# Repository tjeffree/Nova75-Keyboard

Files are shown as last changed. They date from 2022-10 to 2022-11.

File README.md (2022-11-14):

# Nova75

A 75 key ortholinear keyboard designed as a RP2040 powered version of keyboards like the ID75/XD75.

---

## Looks like this
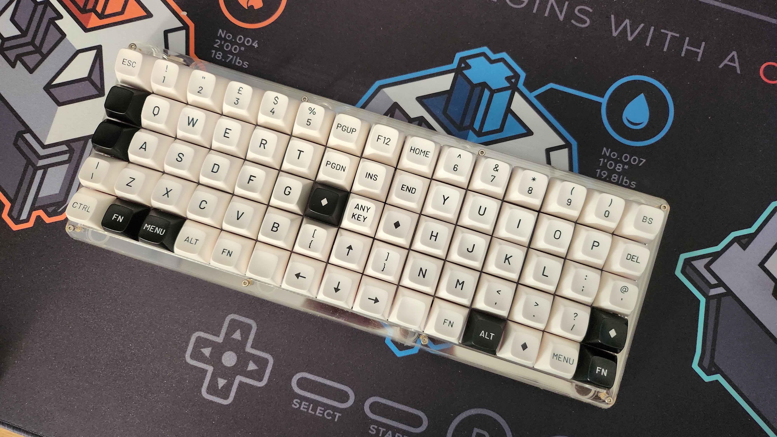
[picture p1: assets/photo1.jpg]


---
## Fab Help

The provided files have been used with JLCPCB. If you're using another fab generate the files according to their specifications.

If you are using JLCPCB (and they have the parts in stock) then head over to JLCPCB and upload the gerber in `jlcpcb/gerber`.

Using mostly the defaults on the order screen check the following:

**Main**
* Dimensions `284.7` x `94.21`
* PCB Color - Whatever you like
* Surface Finish - Whatever you can afford
* Remover Order Number - Specify a location (it's already specified)

**PCB Assembly**
* PCB Assembly - Yes
* Assemble bottom side
* Tooling holes - Added by Customer
* Confirm Parts Placement - Yes

**BOM and Placement**

For the BOM use: `jlcpcb/assembly/BOM-nova75.csv`

For the CPL use: `jlcpcb/assembly/POS-nova75.csv`

Select the PCB description - Office / Keyboard

The next screen should be a list of parts, something like this where you can find out if they have everything:

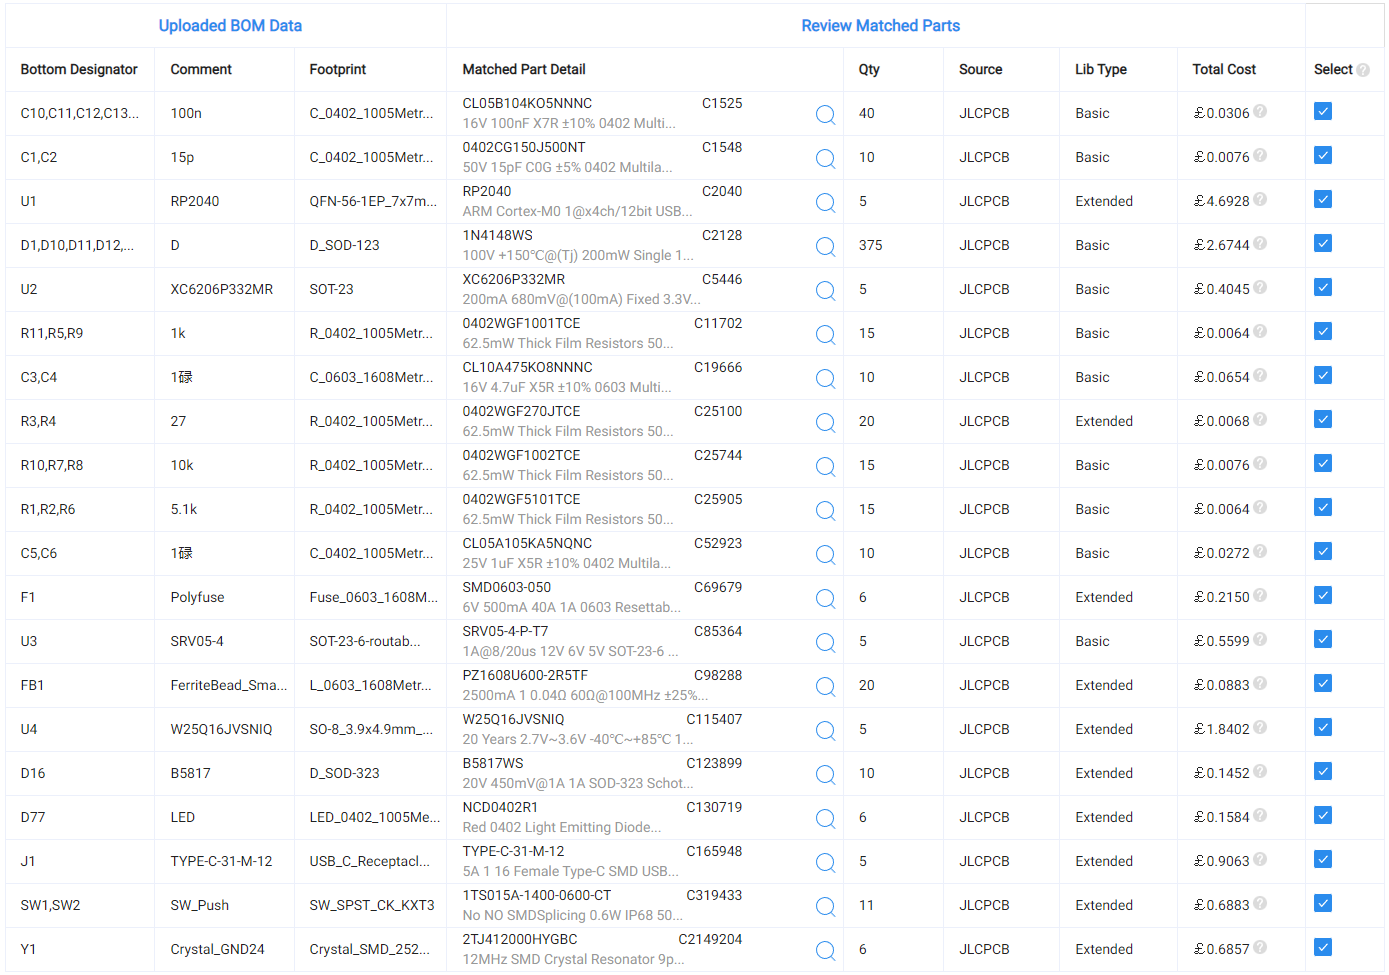
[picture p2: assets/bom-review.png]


Continue on to the placement. Previously all holes lined up, but for some reason JLC preview is not working right now, so the preview will look similar to this with the holes misaligned:

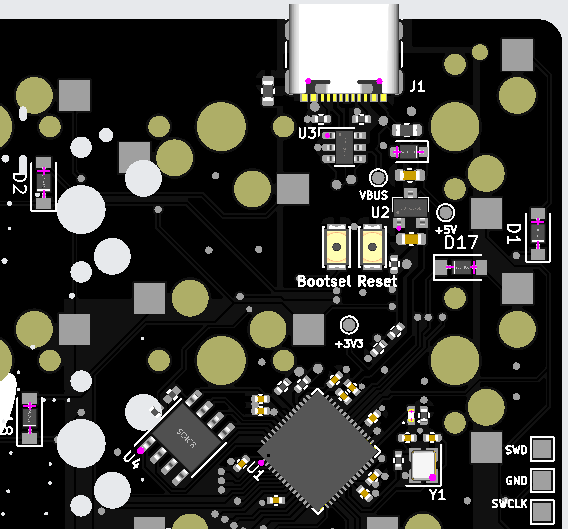
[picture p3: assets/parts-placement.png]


Rotate components the correct way. JLC will check best they can, but you need to do this too.

**That's it. Now wait.**

## Case

The `Case & Plates` dir has some stl files for 3D printing the plates.

Also included is a zip containing the dxf files I sent off for the stacked acrylic case seen below.

## Couple more pictures

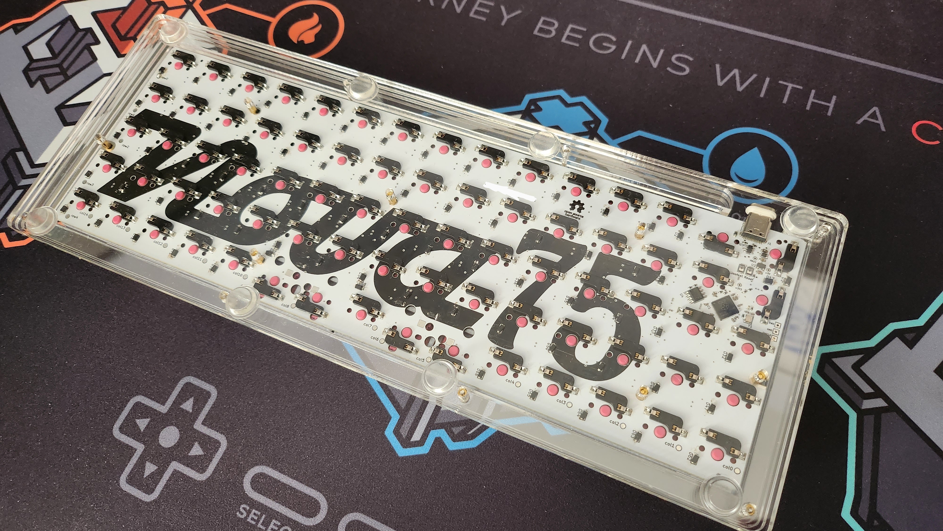
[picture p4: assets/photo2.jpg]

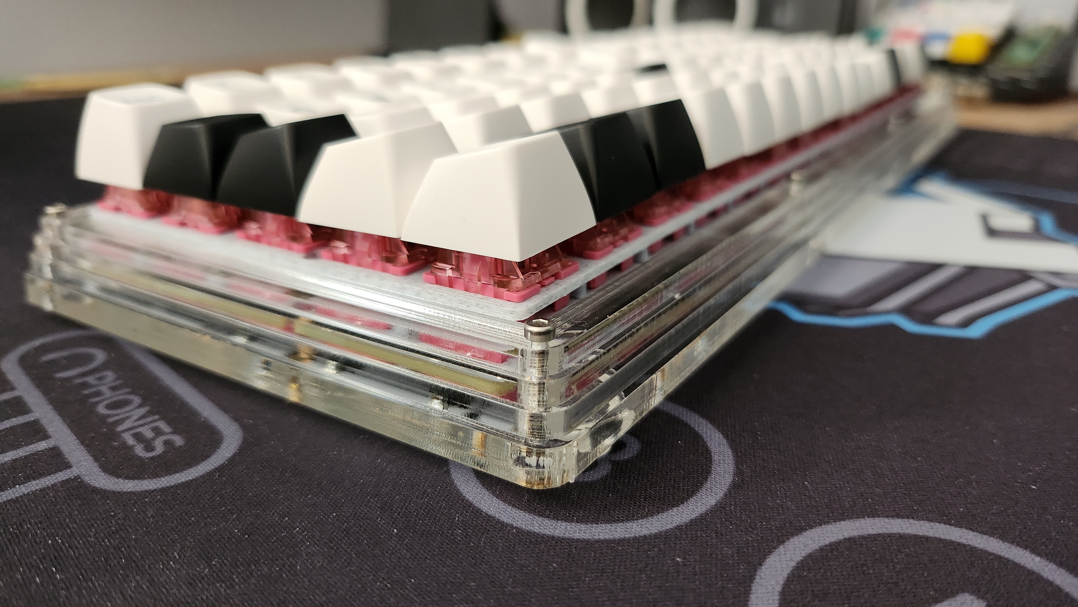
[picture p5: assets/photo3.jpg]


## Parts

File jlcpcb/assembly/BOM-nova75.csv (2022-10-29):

Comment | Designator | Footprint | LCSC
W25Q16JVSNIQ | U4 | SO-8_3.9x4.9mm_P1.27mm | C115407
1k | R11,R5,R9 | R_0402_1005Metric | C11702
B5817 | D16 | D_SOD-323 | C123899
LED | D77 | LED_0402_1005Metric | C130719
100n | C10,C11,C12,C13,C14,C7,C8,C9 | C_0402_1005Metric | C1525
15p | C1,C2 | C_0402_1005Metric | C1548
TYPE-C-31-M-12 | J1 | USB_C_Receptacle_HRO_TYPE-C-31-M-12 | C165948
1µ | C3,C4 | C_0603_1608Metric | C19666
RP2040 | U1 | QFN-56-1EP_7x7mm_P0.4mm_EP3.2x3.2mm | C2040
D | D1,D10,D11,D12,D13,D14,D15,D17,D18,D19,D2,D20,D21,D22,D23,D24,D25,D26,D27,D28,D29,D3,D30,D31,D32,D33,D34,D35,D36,D37,D38,D39,D4,D40,D41,D42,D43,D44,D45,D46,D47,D48,D49,D5,D50,D51,D52,D53,D54,D55,D56,D57,D58,D59,D6,D60,D61,D62,D63,D64,D65,D66,D67,D68,D69,D7,D70,D71,D72,D73,D74,D75,D76,D8,D9 | D_SOD-123 | C2128
Crystal_GND24 | Y1 | Crystal_SMD_2520-4Pin_2.5x2.0mm | C2149204
27 | R3,R4 | R_0402_1005Metric | C25100
10k | R10,R7,R8 | R_0402_1005Metric | C25744
5.1k | R1,R2,R6 | R_0402_1005Metric | C25905
SW_Push | SW1,SW2 | SW_SPST_CK_KXT3 | C319433
1µ | C5,C6 | C_0402_1005Metric | C52923
XC6206P332MR | U2 | SOT-23 | C5446
Polyfuse | F1 | Fuse_0603_1608Metric | C69679
SRV05-4 | U3 | SOT-23-6-routable | C85364
FerriteBead_Small | FB1 | L_0603_1608Metric | C98288
KEYSW | K57 | MXOnly-1U-Hotswap
KEYSW | K72 | MXOnly-1U-Hotswap
KEYSW | K71 | MXOnly-1U-Hotswap
KEYSW | K70 | MXOnly-1U-Hotswap
KEYSW | K69 | MXOnly-2U-Hotswap-ReversedStabilizers
KEYSW | K68 | MXOnly-1U-Hotswap
KEYSW | K66 | MXOnly-2U-Hotswap-ReversedStabilizers
KEYSW | K64 | MXOnly-1U-Hotswap
KEYSW | K63 | MXOnly-1U-Hotswap
KEYSW | K62 | MXOnly-1U-Hotswap
KEYSW | K61 | MXOnly-1U-Hotswap
KEYSW | K60 | MXOnly-1U-Hotswap
KEYSW | K59 | MXOnly-1U-Hotswap
KEYSW | K58 | MXOnly-1U-Hotswap
KEYSW | K56 | MXOnly-1U-Hotswap
KEYSW | K55 | MXOnly-1U-Hotswap
KEYSW | K54 | MXOnly-1U-Hotswap
KEYSW | K53 | MXOnly-1U-Hotswap
KEYSW | K52 | MXOnly-1U-Hotswap
KEYSW | K51 | MXOnly-1U-Hotswap
KEYSW | K50 | MXOnly-1U-Hotswap
KEYSW | K49 | MXOnly-1U-Hotswap
KEYSW | K48 | MXOnly-1U-Hotswap
KEYSW | K47 | MXOnly-1U-Hotswap
KEYSW | K46 | MXOnly-1U-Hotswap
KEYSW | K45 | MXOnly-1U-Hotswap
KEYSW | K44 | MXOnly-1U-Hotswap
KEYSW | K43 | MXOnly-1U-Hotswap
KEYSW | K42 | MXOnly-1U-Hotswap
KEYSW | K41 | MXOnly-1U-Hotswap
KEYSW | K40 | MXOnly-1U-Hotswap
KEYSW | K39 | MXOnly-1U-Hotswap
KEYSW | K38 | MXOnly-1U-Hotswap
KEYSW | K37 | MXOnly-1U-Hotswap
KEYSW | K36 | MXOnly-1U-Hotswap
KEYSW | K35 | MXOnly-1U-Hotswap
KEYSW | K34 | MXOnly-1U-Hotswap
KEYSW | K33 | MXOnly-1U-Hotswap
KEYSW | K32 | MXOnly-1U-Hotswap
KEYSW | K31 | MXOnly-1U-Hotswap
KEYSW | K30 | MXOnly-1U-Hotswap
KEYSW | K29 | MXOnly-1U-Hotswap
KEYSW | K28 | MXOnly-1U-Hotswap
KEYSW | K27 | MXOnly-1U-Hotswap
KEYSW | K26 | MXOnly-1U-Hotswap
KEYSW | K25 | MXOnly-1U-Hotswap
KEYSW | K24 | MXOnly-1U-Hotswap
KEYSW | K23 | MXOnly-1U-Hotswap
KEYSW | K22 | MXOnly-1U-Hotswap
KEYSW | K21 | MXOnly-1U-Hotswap
KEYSW | K20 | MXOnly-1U-Hotswap
KEYSW | K19 | MXOnly-1U-Hotswap
KEYSW | K18 | MXOnly-1U-Hotswap
KEYSW | K17 | MXOnly-1U-Hotswap
KEYSW | K16 | MXOnly-1U-Hotswap
KEYSW | K15 | MXOnly-1U-Hotswap
KEYSW | K14 | MXOnly-1U-Hotswap
KEYSW | K13 | MXOnly-1U-Hotswap
KEYSW | K12 | MXOnly-1U-Hotswap
KEYSW | K11 | MXOnly-1U-Hotswap
KEYSW | K10 | MXOnly-1U-Hotswap
KEYSW | K9 | MXOnly-1U-Hotswap
KEYSW | K8 | MXOnly-1U-Hotswap
KEYSW | K7 | MXOnly-1U-Hotswap
KEYSW | K6 | MXOnly-1U-Hotswap
KEYSW | K5 | MXOnly-1U-Hotswap
KEYSW | K4 | MXOnly-1U-Hotswap
KEYSW | K3 | MXOnly-1U-Hotswap
KEYSW | K2 | MXOnly-1U-Hotswap
KEYSW | K1 | MXOnly-1U-Hotswap
KEYSW | K65 | MXOnly-1U-Hotswap
MountingHole | H6 | MountingHole_2.2mm_M2_elongated
ToolingHole | H5 | Tooling-Hole
KEYSW | K67 | MXOnly-1U-Hotswap
MountingHole | H4 | MountingHole_2.2mm_M2_elongated
ToolingHole | H3 | Tooling-Hole
MountingHole | H2 | MountingHole_2.2mm_M2_elongated
ToolingHole | H1 | Tooling-Hole
MountingHole | H8 | MountingHole_2.2mm_M2_elongated
ToolingHole | H7 | Tooling-Hole
MountingHole | H9 | MountingHole_2.2mm_M2_elongated
TestPoint | TP26 | TestPoint_THTPad_D1.0mm_Drill0.5mm
TestPoint | TP9 | TestPoint_THTPad_D1.0mm_Drill0.5mm
TestPoint | TP8 | TestPoint_THTPad_D1.0mm_Drill0.5mm
TestPoint | TP25 | TestPoint_Pad_D1.5mm
TestPoint | TP24 | TestPoint_Pad_D1.5mm
TestPoint | TP23 | TestPoint_Pad_D1.5mm
TestPoint | TP22 | TestPoint_Pad_D1.5mm
TestPoint | TP21 | TestPoint_Pad_D1.5mm
TestPoint | TP20 | TestPoint_Pad_D1.5mm
TestPoint | TP19 | TestPoint_Pad_D1.5mm
TestPoint | TP18 | TestPoint_Pad_D1.5mm
TestPoint | TP17 | TestPoint_Pad_D1.5mm
TestPoint | TP16 | TestPoint_Pad_D1.5mm
TestPoint | TP15 | TestPoint_Pad_D1.5mm
TestPoint | TP14 | TestPoint_Pad_D1.5mm
TestPoint | TP13 | TestPoint_Pad_D1.5mm
TestPoint | TP12 | TestPoint_Pad_D1.5mm
TestPoint | TP11 | TestPoint_Pad_D1.5mm
TestPoint | TP10 | TestPoint_Pad_D1.5mm
TestPoint | TP7 | TestPoint_THTPad_1.5x1.5mm_Drill0.7mm
TestPoint | TP6 | TestPoint_THTPad_1.5x1.5mm_Drill0.7mm
TestPoint | TP5 | TestPoint_THTPad_1.5x1.5mm_Drill0.7mm
TestPoint | TP4 | TestPoint_Pad_D1.5mm
TestPoint | TP3 | TestPoint_Pad_D1.5mm
TestPoint | TP2 | TestPoint_Pad_D1.5mm
TestPoint | TP1 | TestPoint_Pad_D1.5mm
KEYSW | K76 | MXOnly-1U-Hotswap
KEYSW | K73 | MXOnly-1U-Hotswap
KEYSW | K75 | MXOnly-1U-Hotswap
KEYSW | K74 | MXOnly-1U-Hotswap
KEYSW | K77 | MXOnly-1U-Hotswap

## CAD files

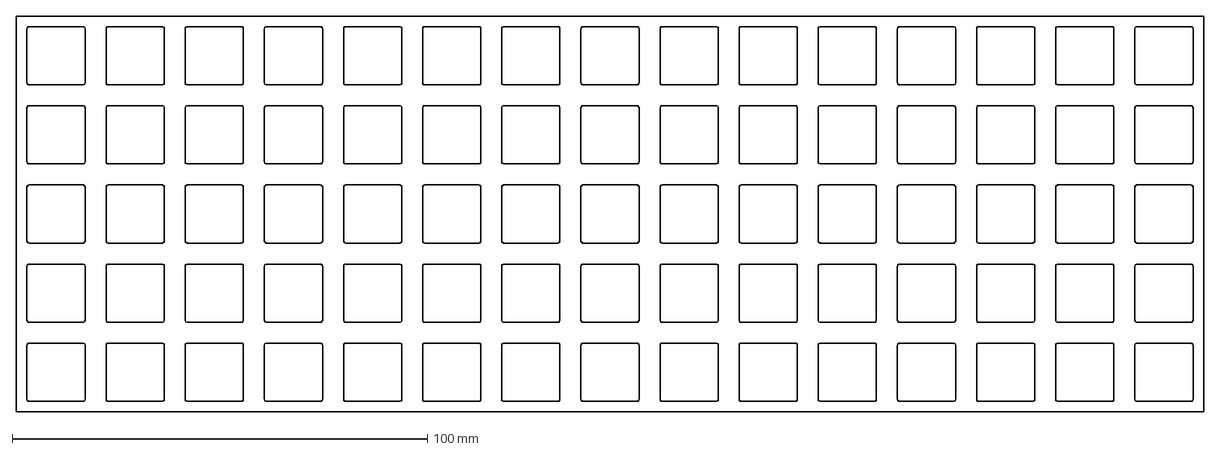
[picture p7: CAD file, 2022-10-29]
assets/plate-2022-09-08T15_52_23.619Z.dxf
285.8 x 95.2 mm

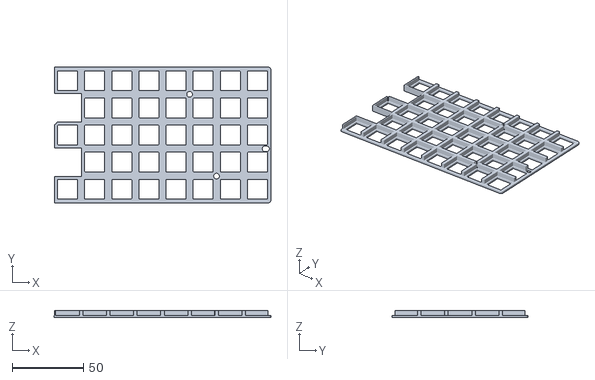
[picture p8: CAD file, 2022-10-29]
Case & Plates/Right.stl
152.4 x 95.2 x 5.00

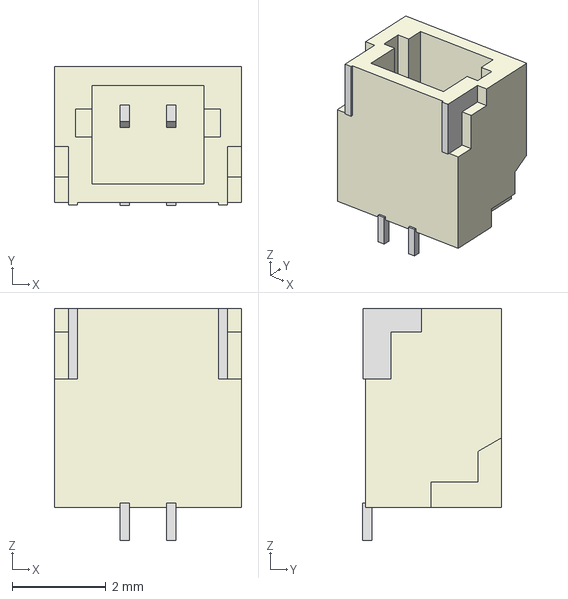
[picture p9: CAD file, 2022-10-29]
marbastlib-main/3d/CON_SM02B-SRSS-TB.step
4.00 x 2.96 x 4.95 mm

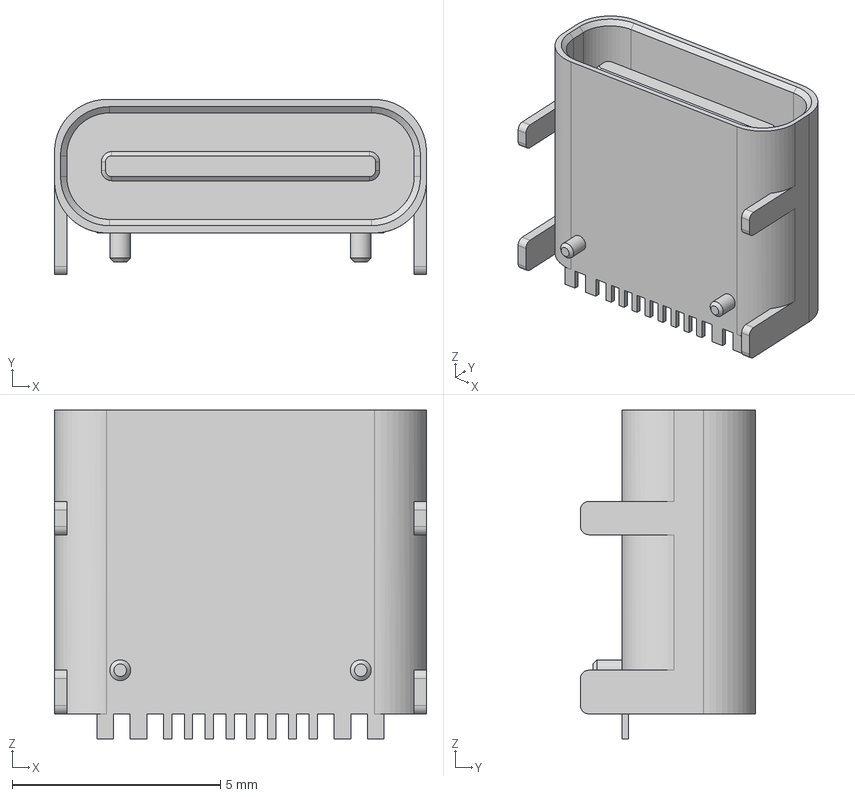
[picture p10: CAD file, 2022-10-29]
Type-C.pretty-master/HRO TYPE-C-31-M-12.step
8.94 x 4.21 x 7.90 mm

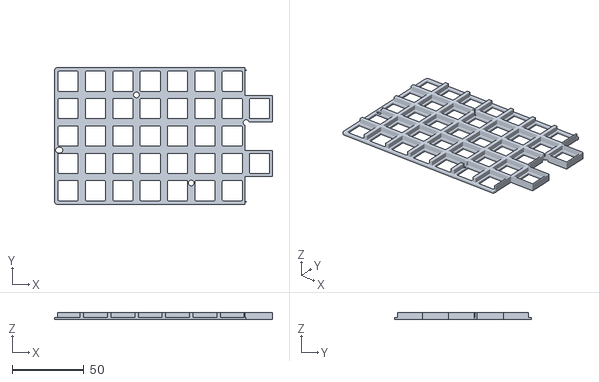
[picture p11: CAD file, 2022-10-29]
Case & Plates/Left.stl
151.8 x 95.2 x 5.00

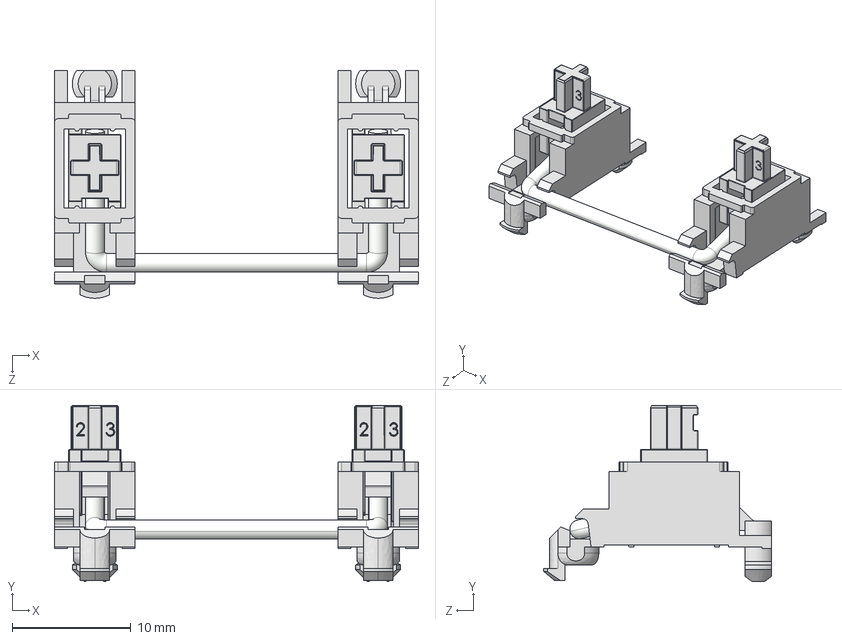
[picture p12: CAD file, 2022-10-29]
local-libraries/Stabilizer - close.STEP
30.7 x 14.9 x 19.2 mm
mx Stabilizer base 16828 x 2
mx Stabilizer key 16828 x 2
metal stick 16828

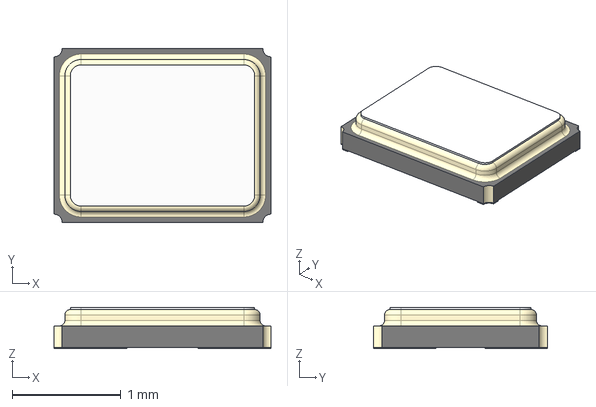
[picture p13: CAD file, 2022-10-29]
marbastlib-main/3d/Crystal_FA-128.step
2.00 x 1.60 x 0.38 mm

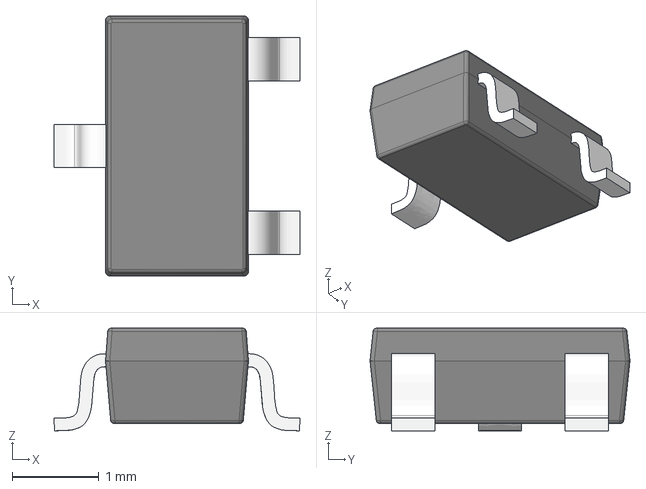
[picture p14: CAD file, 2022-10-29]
local-libraries/SOT23-3.stp
2.84 x 3.00 x 1.18 mm

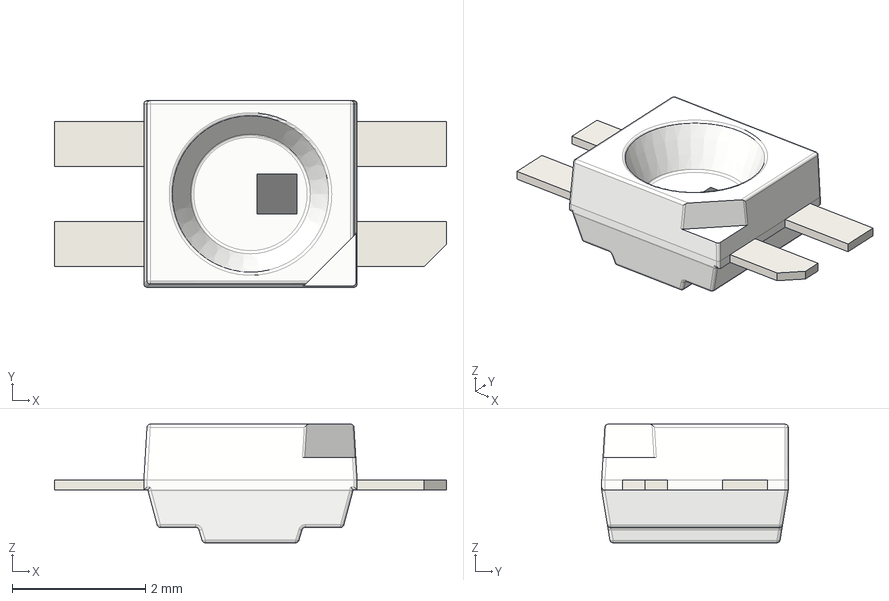
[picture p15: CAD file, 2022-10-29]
marbastlib-main/3d/LED_SK6812MINI-E.step
5.88 x 2.80 x 1.78 mm

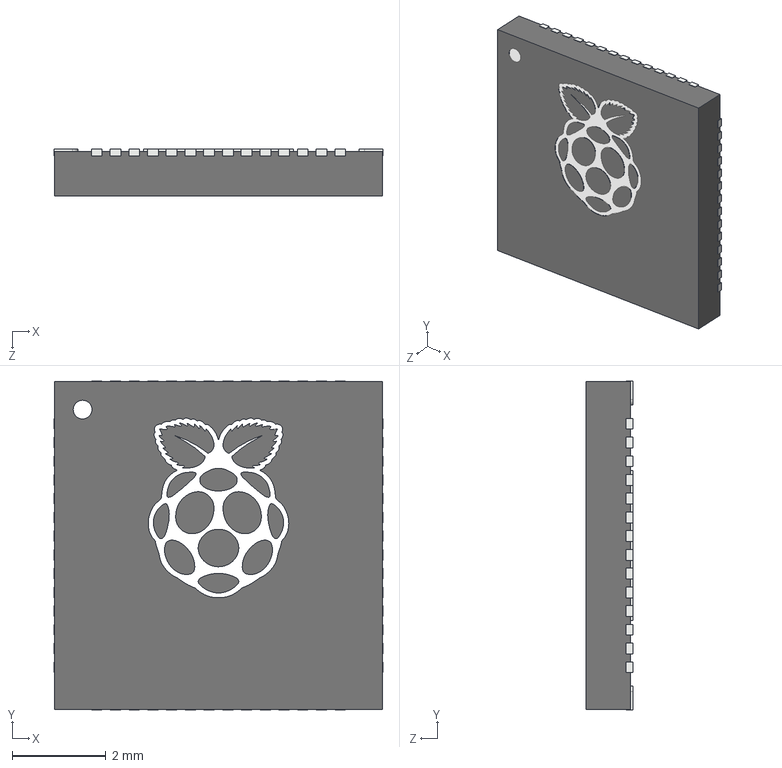
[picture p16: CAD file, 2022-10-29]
local-libraries/RP2040_QFN_PACKAGE.STEP
7.02 x 7.02 x 1.00 mm

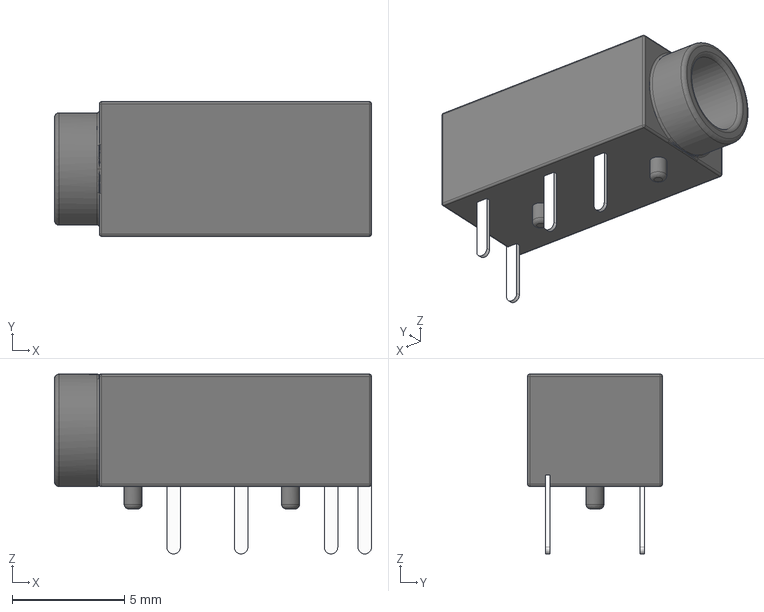
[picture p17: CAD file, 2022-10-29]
marbastlib-main/3d/CON_MJ-4PP-9.step
14.1 x 6.00 x 8.00 mm

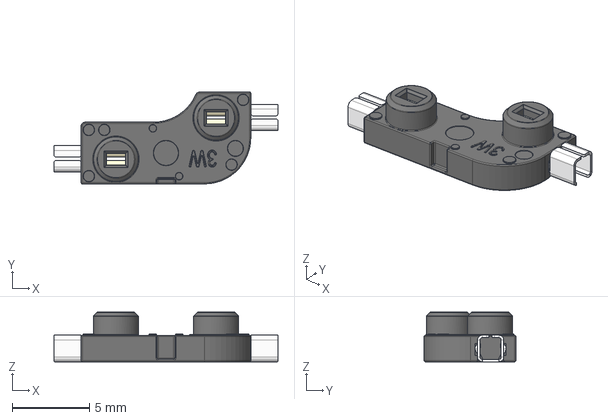
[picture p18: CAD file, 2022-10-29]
local-libraries/Kailh Hotswap MX v22.step
14.5 x 5.95 x 3.22 mm

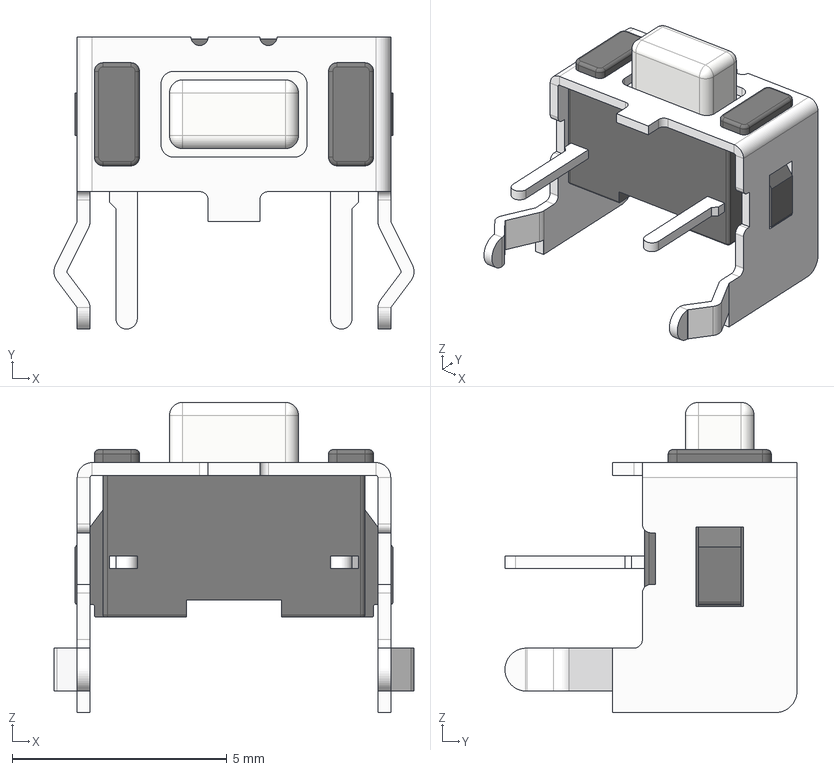
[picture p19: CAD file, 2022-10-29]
marbastlib-main/3d/SW_SKHLLC.step
8.38 x 6.80 x 7.22 mm

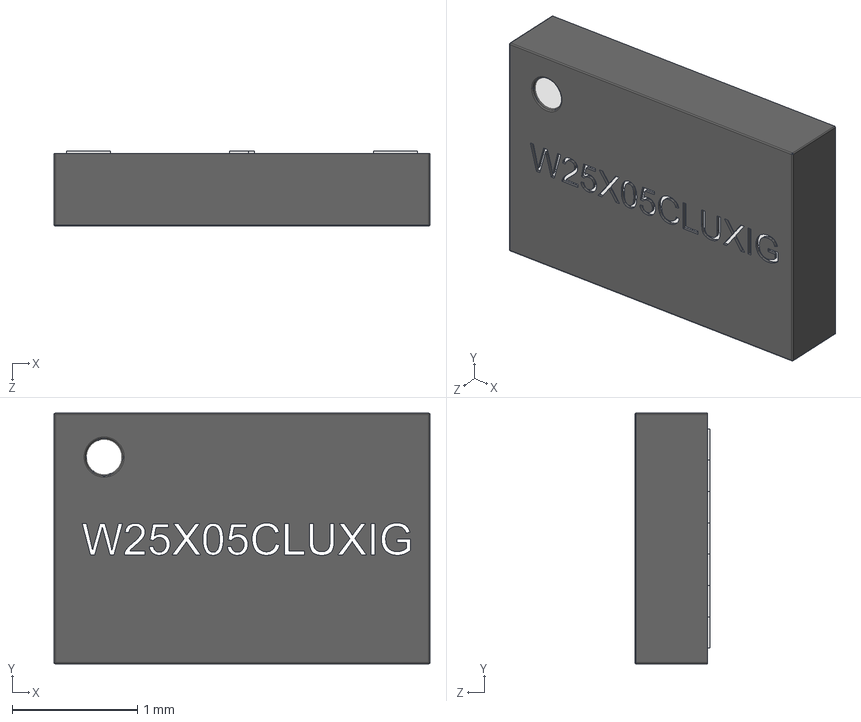
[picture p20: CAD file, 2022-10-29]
local-libraries/W25X05CLUXIG.STEP
3.00 x 2.00 x 0.6 mm

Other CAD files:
marbastlib-main/3d/CON_SM05B-SRSS-TB.step
marbastlib-main/3d/CON_SM13B-SRSS-TB.step
marbastlib-main/3d/LED_WS2812B-MINI.step
marbastlib-main/3d/CON_SM08B-SRSS-TB.step
local-libraries/632723300011.step
marbastlib-main/3d/CON_SM04B-SRSS-TB.step
marbastlib-main/3d/CON_SM06B-SRSS-TB.step
marbastlib-main/3d/CON_SM07B-SRSS-TB.step
marbastlib-main/3d/CON_TYPE-C-31-M-12.step
marbastlib-main/3d/CON_TYPE-C-31-M-14.step
marbastlib-main/3d/HS_Kailh_Choc.step
marbastlib-main/3d/HS_Kailh_MX.step
marbastlib-main/3d/LED_WS2812_2020.step
marbastlib-main/3d/MSK12C02.step
marbastlib-main/3d/ROT_EC11E.step
marbastlib-main/3d/ROT_EC11N.step
marbastlib-main/3d/SW_SSSS213100.step
marbastlib-main/3d/SW_SSSS223900.step
marbastlib-main/3d/Switch_ESP3020.step
marbastlib-main/3d/Switch_MSK12C02.step
marbastlib-main/3d/Switch_SKQG.step
marbastlib-main/3d/holyiot_18010_nRF52840.step
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

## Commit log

2022-10-29 Update production files
    [BOM-nova75.csv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]
2022-11-14 Update PCB
    [nova75.kicad_sch]
2022-11-14 Update fab files
    [nova75-B_Cu.gbl, nova75-B_Mask.gbs, nova75-B_Paste.gbp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]
